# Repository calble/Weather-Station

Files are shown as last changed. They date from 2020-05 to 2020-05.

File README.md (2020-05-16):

# Weather Station
Weather Station is powered by an ESP8266, a BME280, and a DS3231 RTC with a AT25C32 CHIP.
The BME280 and the RTC are connected as follows:
	-- SCL is connected to D1 
	-- SDA is connected to D2.

Upon powerup the board will flash the flash both leds to indicated the last octet of its IP address.
Upon failure to connect to the BME280, led2 will flash in an infinte loop.
Upon completed boot LED1 will be on and LED2 will be off.

## Resetting EEPROM
EEPROM is reset by holding GPIO 3 LOW (Ground).  A message will be printed to the serial monitor about 
resetting progress.  During reset LED1 will be off and LED2 will flash at each of the 256 page
clears. This pattern looks like the LED is mostly on, with short blinks off. Upon completion LED1 will be off and LED2 will flash on and off at a rate of 2Hz for 20 times and then reboot into wifi setup mode.

## URL Enpoints
* / --> GET The main html page for the application
* /get_settings --> POST returns a JSON object with the station, altitude, and remote.
* /save_setttings --> POST saves setting information.  If ssid or password are sent the system will reboot into wifi setup mode.
* /reset_records --> POST resets the high and low records
* /reset_history --> POST resets the historical data
* /json --> GET the JSON representation of what is on /.

## File System
The jar file in the resources directory must be put in the proper Arduino directory to upload
the files.

Make sure you use one of the supported versions of Arduino IDE and have ESP8266 core installed.
Download the tool archive from releases page.
In your Arduino sketchbook directory, create tools directory if it doesn't exist yet. You can find the location of your sketchbook directory in the Arduino IDE at File > Preferences > Sketchbook location.
Unpack the tool into tools directory (the path will look like <sketchbook directory>/tools/ESP8266FS/tool/esp8266fs.jar).
Restart Arduino IDE.

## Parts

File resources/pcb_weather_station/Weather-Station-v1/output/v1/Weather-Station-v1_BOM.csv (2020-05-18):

Quantity | Designators | Value | Device | Package
1 | BB1 |  | BME280 Breakout Board | BME280 Breakout Board
1 | BB2 |  | DS3231 Breakout Board | DS3231 Breakout Board
2 | J1, J2 |  | Generic Pin Header 2.54mm 1x02 ⌀0.9mm | Pin Header 2.54mm 1x02 ⌀0.9mm
1 | R2 |  | R-THT-0207 | R-THT-0207
1 | U1 | ESP8266 (12E) | ESP8266 (12E) | ESP8266 DIP

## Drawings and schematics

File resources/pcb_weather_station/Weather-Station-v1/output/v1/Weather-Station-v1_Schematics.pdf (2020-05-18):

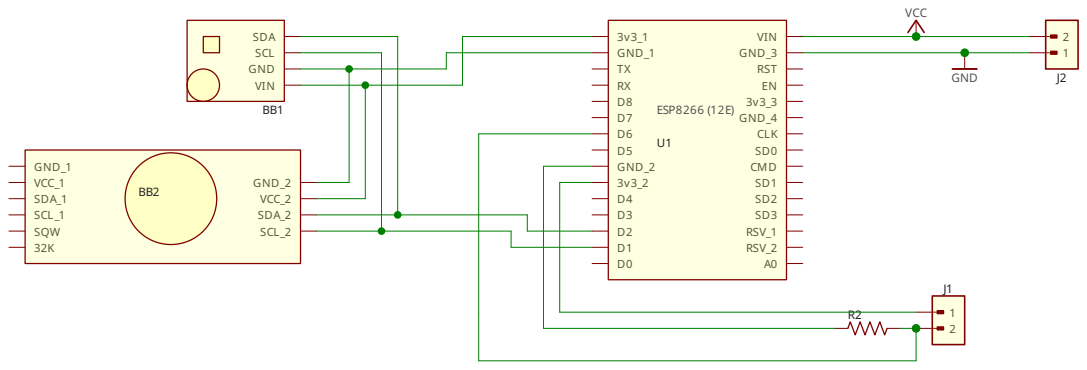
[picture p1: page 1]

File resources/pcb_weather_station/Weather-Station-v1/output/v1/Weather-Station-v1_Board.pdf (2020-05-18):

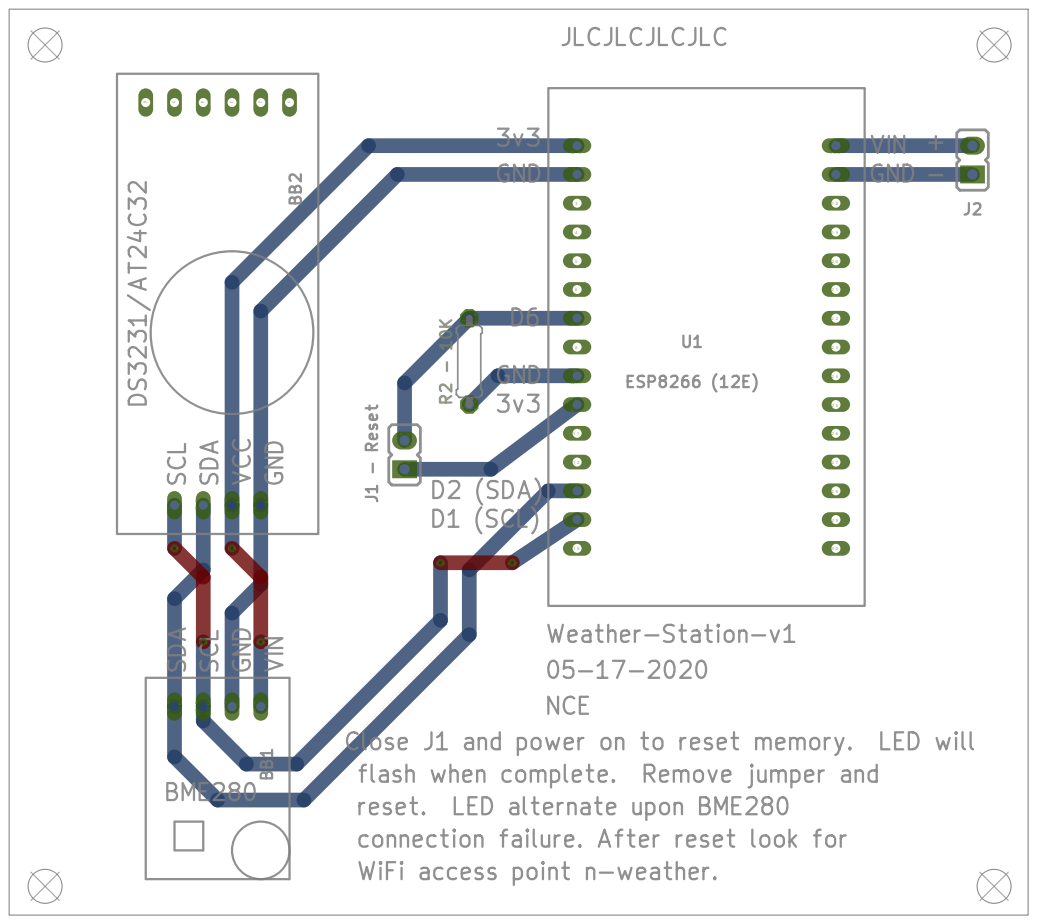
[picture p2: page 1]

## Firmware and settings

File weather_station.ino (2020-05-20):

#include <ESP8266WiFi.h>
#include <Adafruit_Sensor.h>
#include <Adafruit_BME280.h>
#include <Wire.h>
#include <ESP8266WebServer.h>
#include <ESP8266mDNS.h>
#include <TaskScheduler.h>
#include <stdlib.h>
#include <FS.h>
#include <RtcDS3231.h>
#include <EepromAT24C32.h>
#include <ctype.h>

#include "eeprom.h"
#include "wmath.h"
#include "history.h"
#include "settings.h"

ESP8266WebServer server(80);
Adafruit_BME280 bmp;


void handleRoot();
void handleStaticFiles();
void handleJson();
void handleNotFound();
void handleSaveSettings();
void handleGetSettings();
void handleResetRecords();
void handleResetHistory();

void sensorUpdate();
void hourlyUpdate();
void remoteUpdate();
void formatTime(long t, char*);
void flashIP();
char* getPressureRange(int pressure);
char* getTrend();
char* getFrostRisk();


Task sensorTask(10000, TASK_FOREVER, &sensorUpdate);
Task hourlyTask(1000 * 60 * 60, TASK_FOREVER, &hourlyUpdate);
Task remoteTask(1000 * 60 * 10, TASK_FOREVER, &remoteUpdate);
Scheduler runner;
RtcDS3231<TwoWire> Rtc(Wire);
EepromAt24c32<TwoWire> RtcEeprom(Wire);

float currentTemperature;
int currentPressure;
float currentHumidity;

int hour = 0;

Record record;
Setting setting;
DataPoint history[24];

void setup() {
  Serial.begin(115200);
  pinMode(BUILTIN_LED1, OUTPUT); // Initialize the BUILTIN_LED1 pin as an output
  pinMode(BUILTIN_LED2, OUTPUT); // Initialize the BUILTIN_LED2 pin as an output
  pinMode(CLEAR_MEMORY, INPUT);

  Serial.printf("DataPoint Size: %d\n", sizeof(DataPoint));
  Serial.printf("Setting Setting: %d\n", sizeof(Setting));
  Serial.printf("Record Record: %d\n", sizeof(Record));

  //Setup EEPROM
  RtcEeprom.Begin();
  restoreSettings(RtcEeprom, &setting);
  
  //Check memory location 0, if it is zero enter wifi setup mode, otherwise use stored settings.
  if(RtcEeprom.GetMemory(0) == 0){
    IPAddress local_IP(192,168,1,1);
    IPAddress gateway(192,168,1,0);
    IPAddress subnet(255,255,255,0);
    WiFi.softAPConfig(local_IP, gateway, subnet);
    WiFi.softAP("n-weather");
  }else{
    WiFi.mode(WIFI_STA);
    WiFi.begin(setting.ssid, setting.password);
    
    while (WiFi.status() != WL_CONNECTED) {
      delay(500);
      Serial.print(".");
    }
    Serial.println("Connected.");
    Serial.print("Local IP: ");
    Serial.println(WiFi.localIP());
  }
  server.begin();
  MDNS.begin("weather");
  MDNS.addService("http", "tcp", 80);
  MDNS.addService("weather", "tcp", 80);
  MDNS.addService("nSmart","tcp",80);
  
  Wire.begin();
  delay(30);
  if (!bmp.begin(0x76, &Wire)) {
    Serial.println("BME280 failed to connect.");
    while (true) {
      digitalWrite(BUILTIN_LED2, LOW);
      delay(500);
      digitalWrite(BUILTIN_LED2, HIGH);
      delay(500);
      yield();
    }
  }

  //Setup RTC
  Rtc.Begin();
  if (!Rtc.IsDateTimeValid()) {
    Serial.println("RTC IsDateTimeValid False!");
  }
  Rtc.SetIsRunning(true);

  //Clear EEPROM if the pin is high 3 times in a row
//   clearEEPROM(RtcEeprom);
  if (digitalRead(CLEAR_MEMORY) == HIGH) {
    delay(50);
    if (digitalRead(CLEAR_MEMORY) == HIGH) {
      delay(50);
      if (digitalRead(CLEAR_MEMORY) == HIGH) {
        Serial.println("CLEAR PIN was HIGH, RESETTING MEMORY");
        clearEEPROM(RtcEeprom);
      }
    }
  } else {
    Serial.println("CLEAR PIN was LOW, not reseting memory.");
  }

  //Setup server
  server.onNotFound(handleStaticFiles);
  server.on("/", HTTP_GET, handleRoot);
  server.on("/json", HTTP_GET, handleJson);
  server.on("/save_settings", HTTP_POST, handleSaveSettings);
  server.on("/get_settings", HTTP_POST, handleGetSettings);
  server.on("/reset_records", HTTP_POST, handleResetRecords);
  server.on("/reset_history", HTTP_POST, handleResetHistory);
  server.begin();

  //Schedule tasks
  runner.init();
  runner.addTask(sensorTask);
  runner.addTask(hourlyTask);
  runner.addTask(remoteTask);
  sensorTask.enable();
  hourlyTask.enable();
  remoteTask.enable();
  //Setup flash memory file system
  SPIFFS.begin();

  //Clear out all data
  currentTemperature = 0;
  currentPressure = 0;
  currentHumidity = 0;

  hour = 0;
  
  restoreHistory(RtcEeprom, history);
  //You must restore hour to the proper value or no historical data will be sent via JSON
  for(int i=23; i >=0; i--){
    if(history[i].time != 0){
      hour++;
    }else{
      break;
    }
  }
  Serial.printf("Current HOUR: %d\n", hour);
  restoreRecords(RtcEeprom, &record);
  yield();
  Serial.println("HISTORY DATA:");
  for (int i = 0; i < 24; i++) {
    Serial.printf("#%02d: %ld, %f, %f, %d\n",i, history[i].time, history[i].temperature, history[i].humidity, history[i].pressure);
  }
  Serial.println("Settings:");
  Serial.printf("SSID: %s, PASSWORD: XXX, REMOTE: %s, STATION: %s, ALTITUDE: %f\n", setting.ssid, setting.remote, setting.station, setting.altitude);
  Serial.println("Records:");
  Serial.printf("MAX T: %f, MIN T: %f, MAX H: %f, MIN H: %f, MAX P: %d, MIN P: %d\n", record.maxTemperature, record.minTemperature, record.maxHumidity, record.minHumidity, record.maxPressure, record.minPressure);
  
  flashIP();
}

void loop() {
  server.handleClient();
  runner.execute();
  MDNS.update();
}

void handleRoot() {
  File file = SPIFFS.open("/index.htm", "r");
  server.streamFile(file, "text/html");
  file.close();
}

void handleJson() {
  server.setContentLength(4000);
  int len = 0;
  
  server.send(200, "text/json", "");
  Serial.println("Handling JSON");
  float p = currentPressure / 100.0;
  char *jsonStart = (char*)"{'station':'%s',\n'current':{\n\t'temperature':%0.2f,\n\t'humidity':%0.2f,\n\t'barometer':%0.2f,\n\t'pressure':'%s',\n\t'trend':'%s',\n\t'time':'%s',\n\t'frost':%s\n},\n'records':{\n\t'temperature':{'high':%0.2f,'low':%0.2f},\n\t'humidity':{'high':%0.2f,'low':%0.2f},\n\t'barometer':{'high':%0.2f,'low':%0.2f}\n},\n'history':[\n";
  char *h = (char*)"\t{\n\t\t'time':'%s',\n\t\t'temperature':%0.2f,\n\t\t'humidity':%0.2f,\n\t\t'barometer':%0.2f\n\t}";
  char *jsonEnd = (char*)"\n]\n}";
  
  replaceStr(jsonStart, '\'', '\"');
  replaceStr(h, '\'', '\"');
  replaceStr(jsonEnd, '\'', '\"');
  
  char buffer[2000];
  buffer[0] = '\0';

  //JSON Start
  RtcDateTime t = Rtc.GetDateTime();
  char time[18];
  int currentHour = t.Hour();
  if(t.Hour() == 0){
    currentHour = 12;
  }
  sprintf(time, "%04d-%02d-%02d %02d:%02d", t.Year(), t.Month(), t.Day(), currentHour, t.Minute());
  sprintf(buffer, jsonStart,  setting.station, cToF(currentTemperature), currentHumidity, currentPressure / 100.0, getPressureRange(currentPressure), getTrend(), time, getFrostRisk(), cToF(record.maxTemperature), cToF(record.minTemperature), record.maxHumidity, record.minHumidity, record.maxPressure / 100.0, record.minPressure / 100.0);
  len += strlen(buffer);
  server.sendContent(buffer, strlen(buffer));

  //JSON History
  int count = (hour < 24) ? 24 - hour : 0;
  for (int i = count; i < 24; i++) {
    char b[200];
    char t[18];
    formatTime(history[i].time, t);
    Serial.printf("History: #%d(Time %s, Temp: %d, Hum: %d, Pres: %d)\n", i, t, cToF(history[i].temperature), history[i].humidity, history[i].pressure);
    sprintf(b, h, t, cToF(history[i].temperature), history[i].humidity, history[i].pressure / 100.0);
    if(i != 23){
      strcat(b, ",\n");
    }
    int hLen = strlen(b);
    server.sendContent(b, hLen);
    len += hLen; 
  }

  //JSON End
  int endLen = strlen(jsonEnd);
  len += endLen;
  server.sendContent(jsonEnd, endLen);

  char blank[100];
  for(int i=0; i < 100; i++){
    blank[i] = ' ';
  }
  
  for(int i=len; i < 4000; i+=100){
    server.sendContent(blank, 100);
//    Serial.printf("%d...\n", i);
  }
  if(len % 100 != 0){
    server.sendContent(blank, len % 100);
  }
}

void handleStaticFiles() {
  if (SPIFFS.exists(server.uri())) {
    String contentType;
    if (server.uri().endsWith(".htm")) {
      contentType = "text/html";
    } else if (server.uri().endsWith(".css")) {
      contentType = "text/css";
    } else if (server.uri().endsWith(".js")) {
      contentType = "text/javascript";
    } else if (server.uri().endsWith(".png")) {
      contentType = "image/png";
    } else if (server.uri().endsWith(".ico")) {
      contentType = "image/png";
    } else if (server.uri().endsWith(".gif")) {
      contentType = "image/gif";
    } else {
      //We don't server any other type of file
      server.send(401, "text/html", "<!DOCTYPE html><html lang=\"en\"><head><meta charset=\"UTF-8\"><title>Weather Station</title></head><body><h1>Weather Station</h1><h2>401 Unauthorized!</h2></body></html>");
      return;
    }
    File file = SPIFFS.open(server.uri(), "r");
    server.streamFile(file, contentType);
    file.close();
  } else {
    //File does not exist
    server.send(404, "text/html", "<!DOCTYPE html><html lang=\"en\"><head><meta charset=\"UTF-8\"><title>Weather Station</title></head><body><h1>Weather Station</h1><h2>404 File Not Found!</h2></body></html>");
  }
}

void handleSaveSettings() {
  String message = "success";
  
  if(server.hasArg("action") && server.arg("action") == "save"){
    boolean shouldRestart = false;
    
    if(server.hasArg("ssid") && server.arg("ssid") != ""){
      String ssid = server.arg("ssid");
      if(ssid.length() > 32){
        ssid = ssid.substring(0, 32);
      }
      strcpy(setting.ssid, ssid.c_str());
      shouldRestart = true;  
    }
    if(server.hasArg("password") && server.arg("password") != ""){
      String password = server.arg("password");
      if(password.length() > 64){
        password = password.substring(0, 64);
      }
      strcpy(setting.password, password.c_str());
      shouldRestart = true;  
    }

    if(server.hasArg("remote") && server.hasArg("station") && server.hasArg("altitude") && server.hasArg("date") && server.hasArg("time")){
      String remote = server.arg("remote");
      String station = server.arg("station");

      if(station.length() > 32){
        station = station.substring(0,32);
      }
      strcpy(setting.station, station.c_str());
      
      if(remote.length() > 64){
        remote = remote.substring(0,64);
      }
      strcpy(setting.remote, remote.c_str());
      
      float altitude = atof(server.arg("altitude").c_str());
      setting.altitude = altitude;

      String nDate = server.arg("date");
      String nTime = server.arg("time");
      
      int y = atoi(nDate.substring(0,4).c_str());
      int m = atoi(nDate.substring(5,7).c_str());
      int d = atoi(nDate.substring(8,10).c_str());
      int h = atoi(nTime.substring(0,2).c_str());
      int M = atoi(nTime.substring(3,5).c_str());
      
      RtcDateTime newDateTime(y,m,d,h,M,0);
      Rtc.SetDateTime(newDateTime);
     
    }else{
      message = "missing fields";
    }
    saveSettings(RtcEeprom, setting);
    
    if(shouldRestart){
      Serial.println("SSID or Password have changed, restarting.");
      //If the SSID or Password has changed then set memory location 0 to a non zero value.
      //This tells the device to start wifi using stored Settings.
      //When memory address zero is zero, the wifi starts in AP mode so that it can be setup.
      RtcEeprom.SetMemory(0, 255);
      
      server.send(200,"text/json","{\"response\":\"rebooting\"}");
      server.client().stop();
      ESP.restart();
      return;
    }
    server.send(200,"text/json","{\"response\":\""+message+"\"}");
    return;
  }
  server.send(400, "text/json", "{\"response\":\"Bad Request\"}");
}

void handleResetRecords() {
  if(server.hasArg("action") && server.arg("action") == "reset"){
    record.maxTemperature = -201;
    record.minTemperature = 202;
    record.maxPressure = -200003;
    record.minPressure = 200004;
    record.maxHumidity = -205;
    record.minHumidity = 206;

    resetHighLow(RtcEeprom);

    server.send(200, "text/json", "{\"response\":\"success\"}");
    return;
  }
  server.send(400, "text/json", "{\"response\":\"bad request\"}");
}

void handleResetHistory() {
  if(server.hasArg("action") && server.arg("action") == "reset"){
    for (int i = 0; i < 24; i++) {
      history[i].time = 0;
      history[i].temperature = 0;
      history[i].humidity = 0;
      history[i].pressure = 0;
    }
    hour = 0;
    resetHistory(RtcEeprom);
    hourlyUpdate();
    server.send(200, "text/json", "{\"response\":\"success\"}");
    return;
  }
   server.send(400, "text/json", "{\"response\":\"bad request\"}");
}

void sensorUpdate() {
  currentTemperature = bmp.readTemperature();
  currentHumidity = bmp.readHumidity();
  currentPressure = pressureAtSealevel();

  Serial.printf("Sensor Update: %0.2fc, %0.2f%%, %0.2fmBar\n", currentTemperature, currentHumidity, currentPressure / 100.0);
  boolean flag = false;
  if (currentTemperature > record.maxTemperature) {
    record.maxTemperature = currentTemperature;
    flag = true;
  }
  if (currentTemperature < record.minTemperature) {
    record.minTemperature = currentTemperature;
    flag = true;
  }


  if (currentPressure > record.maxPressure) {
    record.maxPressure = currentPressure;
    flag = true;
  }
  if (currentPressure < record.minPressure) {
    record.minPressure = currentPressure;
    flag = true;
  }


  if (currentHumidity > record.maxHumidity) {
    record.maxHumidity = currentHumidity;
    flag = true;
  }
  if (currentHumidity < record.minHumidity) {
    record.minHumidity = currentHumidity;
    flag = true;
  }

  if (flag) {
    saveRecords(RtcEeprom, record);
  }
}

void hourlyUpdate() {
  Serial.println("Hourly Update");
  for (int i = 1; i < 24; i++) {
    history[i-1].temperature = history[i].temperature;
    history[i-1].pressure = history[i].pressure;
    history[i-1].humidity = history[i].humidity;
    history[i-1].time = history[i].time;
  }

  history[23].temperature = currentTemperature;
  history[23].pressure = currentPressure;
  history[23].humidity = currentHumidity;
  history[23].time = Rtc.GetDateTime().TotalSeconds();
  hour++;
  saveHistory(RtcEeprom, history);
}

void flashIP() {
  Serial.printf("LAST: %d\n", WiFi.localIP()[3]);
  int ip = WiFi.localIP()[3];
  int digits[3] = {ip / 100, ip / 10 % 10, ip % 10};

  digitalWrite(BUILTIN_LED1, HIGH);
  digitalWrite(BUILTIN_LED2, HIGH);
  delay(4000);
  for (int i = 0; i < 3; i++) {
    for (int j = 0; j < digits[i]; j++) {
      digitalWrite(BUILTIN_LED1, LOW);
      digitalWrite(BUILTIN_LED2, LOW);
      delay(300 * 3);
      digitalWrite(BUILTIN_LED1, HIGH);
      digitalWrite(BUILTIN_LED2, HIGH);
      delay(300);

    }
    delay(2500);
  }

  digitalWrite(BUILTIN_LED1, LOW);
  digitalWrite(BUILTIN_LED2, HIGH);
}

int pressureAtSealevel() {
  int pressure = bmp.readPressure();
  return pressure / pow(1 - setting.altitude / 44330.0, 5.255);
}

void handleGetSettings() {
  char* tpl = (char*)"{\"station\":\"%s\",\n\"remote\":\"%s\",\n\"altitude\":%0.2f,\n\"time\":\"%04d-%02d-%02d %02d:%02d\"}";
  char buffer[250];
  RtcDateTime d = Rtc.GetDateTime();
  int hour  = d.Hour();
  if(d.Hour() == 0){
    hour = 12;
  }
  sprintf(buffer, tpl, setting.station, setting.remote, setting.altitude, d.Year(), d.Month(), d.Day(), hour, d.Minute());
  server.send(200,"text/json", buffer);
}

void remoteUpdate() {
  if (strlen(setting.remote) != 0) {
    //Step 1: form JSON data
//    char* fmt = (char*) "{\"station\":\"%s\", \"time\":\"%04d-%02d-%02d %02d:%02d\", \"currentTemperature\":%0.2f, \"currentHumidity\":%0.2f, \"currentPressure\":%0.2f, \"frost\":%s}";
//    char buffer[1000];
//    
//    RtcDateTime d = Rtc.GetDateTime();
//    sprintf(buffer, fmt, setting.station, d.Year(), d.Month(), d.Day(), d.Hour(), d.Minute(), currentTemperature, currentHumidity, currentPressure, getFrostRisk());
//    
    //Step 2: resolve mDNS host if needed
//    if(setting.remote, (char*)".local"){
//      
//    }else{
//      
//    }
    //Step 3: send data to remote server
  }
}

char* getPressureRange(int pressure) {
  if (pressure > 102268) {
    return (char*)"High Pressure";
  } else if (pressure > 100914) {
    return (char*)"Normal Pressure";
  } else {
    return (char*)"Low Pressure";
  }
}

char* getTrend() {
  if (hour < 10) {
    return (char*)"Unknown";
  }

  int change = currentPressure  - (history[17].pressure + history[18].pressure + history[19].pressure) / 3;

  if (change >= 600) {
    return (char*)"very rapidly rising";
  } else if (change >= 360) {
    return (char*)"rapidly rising";
  } else if (change >= 160) {
    return (char*)"rising";
  } else if ( change >= 15) {
    return (char*)"slowly rising";
  } else if (change < 15 && change > -15) {
    return (char*)"steady";
  } else if (change < -600) {
    return (char*)"very rapidly falling";
  } else if (change <= -360) {
    return (char*)"rapidly falling";
  } else if (change <= -160) {
    return (char*)"falling";
  } else {
    return (char*)"slowly falling";
  }
}

char* getFrostRisk() {
  if (currentTemperature < 1 || (hour >= 3 && history[23].temperature < 1 && history[22].temperature < 1 && history[21].temperature < 1)) {
    return (char*)"true";
  }
  return (char*)"false";
}

void formatTime(unsigned int t, char* sTime) {
  RtcDateTime d(t);
  Serial.printf("Format: %04d-%02d-%02d %02d:%02d", d.Year(), d.Month(), d.Day(), d.Hour(), d.Minute());
  sprintf(sTime, "%04d-%02d-%02d %02d:%02d", d.Year(), d.Month(), d.Day(), d.Hour(), d.Minute());
}

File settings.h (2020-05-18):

#ifndef SETTINGS
#define SETTINGS

#define ADDR_SETUP           0   //  1 byte, if zero run setup, otherwise run like normal
#define ADDR_RECORD         32   // 24 bytes
#define ADDR_SETTING        64   //204 bytes
#define ADDR_HISTORY        288  //384 bytes

#define BUILTIN_LED1 2 //GPIO2
#define BUILTIN_LED2 16//GPIO16
#define CLEAR_MEMORY D6

struct DataPoint {
  //Time is the number of seconds since 2000.
  unsigned int time;
  float temperature;
  float humidity;
  int pressure;
};

struct Setting {
  char ssid[33];
  char password [65];
  float altitude;
  char station[33];
  char remote[65];
};

struct Record {
  float maxTemperature;
  float minTemperature;

  int maxPressure;
  int minPressure;

  float maxHumidity;
  float minHumidity;
};

#endif

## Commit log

2020-04-15 Initial Commit of Weather Station. Powered by an ESP8266 and a BMP180.
2020-04-16 -- Fixed bug in generateArray that caused it to return bogus data. -- Added feature so that the last octet of the IP address is flashed by the on board LEDs on boot.
    [weather_station.ino]
2020-04-17 updated program to use different trend logic. Updated graph and table to use the temp and pressure arrays where new data is added onto the end of the array and old data is shifted to the left.
2020-04-21 Added mDNS to software so that it can be reached via weather.local. Attempted to fix crashing issue. Need to look into uploading files to the chip and serving those files.
    [weather_station.ino]
2020-04-23 Updated code to monitor pressure at sea level instead of reporting absolute pressure.
2020-04-23 Change Log: -- Fixed logic error in trend function -- Moved static assets to SPIFFS -- Fixed spacing issue in time series data -- Add range data to time series data -- Removed C temperature measureme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
    [weather_station.ino]
2020-04-24 The following changes were made: -- Favicon added -- CSS for current weather updated, added media query for mobile -- Updated graph so that it renders based on data available -- Updated ranges so tha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
2020-04-24 Changes: -- Added form submit confirmation on resetting data -- Update css for reset button -- Added reset icon to svg file, but it unused as this time -- Fixed html error in generateTable function
    [weather_station.ino]
2020-05-01 Updated trend logic, so that it will display low/normal/high pressure even if trend data is not available.
2020-05-02 Changed min, max, and range to return a float. This fixes the bug where the temperature graph would have bars that would be too tall.
    [weather_station.ino]
2020-05-05 Fixed recurring bug where historic data graph for temperature was frequenlty too tall. It turns out that the built in abs function returns an integer and was truncatig range.
    [weather_station.ino]
2020-05-15 Fixed bug in hourlyUpdate where it was aliasing previus DataPont elements instead of cloning data. Fixed issue where historical temperatures where in C instead of freedom loving F.
    [weather_station.ino]
2020-05-15 Fixed bug where record min and max temperature would be shown in C instead of F.
    [weather_station.ino]
2020-05-15 Fixed bug where min and max record values were swapped, fixed bug where default record low pressure was not low enough.
    [weather_station.ino]
2020-05-15 Added units to history table and unit to temperature in Current Conditions.
2020-05-15 Updated program so support saving settings to ram and resetting records and historical data.
    [history.cpp, weather_station.ino]
2020-05-15 Fixed bug in hourlyUpdate where it was replicating the last hour's updates across the history array. Implemented some helper function for reading and writing to eeprom
    [eeprom.cpp, history.cpp, settings.h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]
2020-05-16 Fixed bugs in read/write bytes to eeprom functions
    [eeprom.cpp, history.cpp, weather_station.ino]
2020-05-16 Fixed bug where History test was rewriting history every time the device reboot.
    [weather_station.ino]
2020-05-16 fixed bug where records where being saved to wrong memory location. Improved reset historical data so that after a reset an hourlyUpdate is executed.
    [history.cpp, weather_station.ino]
2020-05-18 Initial commit of the PCB for the weather station
    [Weather-Station-v1_BOM.csv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]
2020-05-18 Updated weather_station.ino to support the reset pin. Updated settings.h to reference D6 as the reset pin. Updated history.cpp to no longer restart the esp after a memory clear. Updated the PCB.
    [Weather-Station-v1.gbl, Weather-Station-v1.gbo, Weather-Station-v1.gbs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]
2020-05-18 Updated so that the wifi password is no longer printed out on the serial line.
    [weather_station.ino]
2020-05-18 Moved text on PCB to silkscreen layout
    [Weather-Station-v1.gbl, Weather-Station-v1.gbo, Weather-Station-v1.gbs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]
2020-05-18 Updated pcb hole size and silkscreen markings
    [Weather-Station-v1.gbl, Weather-Station-v1.gbo, Weather-Station-v1.gbs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]
2020-05-18 Updated the pdfs for pcb and schematics
2020-05-19 Fixed bug where 12:34am would be shown as 0:34am
    [weather_station.ino]
2020-05-20 Fixed bug that was introducted in last commit. the hour variable was being overriden locally and this cause only some of the historical data to be displayed.
    [weather_station.ino]
